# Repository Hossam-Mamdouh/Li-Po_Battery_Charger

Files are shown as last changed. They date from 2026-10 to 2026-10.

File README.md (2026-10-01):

PowerCore 3V3

USB-C 1S Li-Po Power Management & 3.3 V Supply PCB

PowerCore 3V3 is a compact power-management board for a single-cell
Li-Po battery. It combines USB-C input, Li-Po charging, system
power-path management, battery protection, and a regulated 3.3 V output.

Features

USB-C 5 V power input

1S Li-Po battery support

MCP73871 charger with system power-path management

DW01A + FS8205A battery protection

TPS63802 buck-boost regulator

Regulated 3.3 V output

Designed for up to 500 mA system load

Approximately 500 mA maximum programmed charge current

USB input PTC protection

Charge/status indication LEDs

Power Architecture

USB-C 5 V
    |
    v
Input Protection
    |
    v
MCP73871 Charger + Power Path
    |                    |
    v                    v
1S Li-Po               VSYS
    |                    |
    v                    v
DW01A + FS8205A      TPS63802
Battery Protection   Buck-Boost
                         |
                         v
                       3.3 V
                         |
                         v
                    System Load

Main Components

Reference   Component      Function

U2          MCP73871       Li-Po charger and power-path controller
U3          DW01A          Battery protection controller
Q1          FS8205A        Dual N-channel MOSFET protection switch
U4          TPS63802       Buck-boost regulator
F1          1.5 A PTC      USB input over-current protection
J1          USB-C          5 V power input
Battery     JST-PH 2-pin   1S Li-Po connection

Charger Configuration

Charge Current

PROG1 = 2 kΩ

Programs approximately 500 mA maximum charge current.

The actual charging current is reduced when system load consumes part of
the available input power.

Termination Current

PROG3 = 20 kΩ

Sets approximately 50 mA termination current.

Input Current Mode

SEL = +5V_USB

The charger uses the higher-current adapter mode rather than the 500 mA
USB mode.

Other Settings

CE pulled high → charging enabled

TE# tied to GND → safety timer enabled

THERM uses a fixed 10 kΩ resistor to GND

VPCC tied to +5V_USB

PROG2 pulled high through 10 kΩ

PG# pulled high through 10 kΩ

STAT1 / STAT2 provide status indication

Battery Protection

The protection stage uses a DW01A controller and FS8205A dual MOSFET.

For the selected FUXINSEMI FS8205A:

Pin 1 → S1
Pin 2 → D1/D2
Pin 3 → S2
Pin 4 → G2
Pin 5 → D1/D2
Pin 6 → G1

Pins 2 and 5 are the common drain connection and must be electrically
connected.

External connections:

Q1 S1      → B-
Q1 S2      → GND / P-
Q1 G1      → DW01A OD
Q1 G2      → DW01A OC
Q1 D1/D2   → common drain node

DW01A current sense:

CSI → 1 kΩ → GND / P-

3.3 V Regulation

The TPS63802 maintains a regulated 3.3 V rail from the 1S battery/system
rail.

Intended load: 500 mA

Inductor: 0.47 µH

Input capacitor: 10 µF

Output capacitor: 22 µF

Feedback: 511 kΩ / 91 kΩ

EN: VSYS

MODE: GND

The buck-boost topology allows 3.3 V regulation as battery voltage moves
above and below the output voltage.

USB-C Interface

The USB-C connector is configured as a power input.

CC1 → 5.1 kΩ → GND
CC2 → 5.1 kΩ → GND

Input decoupling and transient protection are included.

Battery Connector

The current schematic uses:

Battery Pin 2 → VBAT (+)
Battery Pin 1 → B- (-)

JST-PH pin numbering does not inherently define battery polarity. Verify
the actual battery cable/mating connector pinout before connection.

Clearly mark + and − on the PCB.

Power Budget

The intended system load is:

3.3 V × 500 mA = 1.65 W

The programmed 500 mA battery charge current is a maximum. Actual charge
current depends on system load, USB supply capability, regulator
efficiency, and charger operating conditions.

PCB Layout Guidelines

Keep TPS63802 input/output capacitors close to the IC.

Keep the 0.47 µH inductor close to the switching pins.

Keep the FB trace away from switching nodes.

Use short, low-impedance high-current paths.

Place USB input protection close to the USB-C connector.

Use appropriate copper width for battery and system power paths.

Provide solid ground copper and thermal areas.

Clearly mark battery polarity.

Design Status

Revision: A
Status: Prototype / Engineering Design

Before manufacturing, verify:

Schematic ERC

PCB DRC

Q1 symbol-to-footprint pin mapping

Battery connector pinout

PTC fuse rating and thermal derating

USB-C input capability

TPS63802 thermal performance

Charger behavior under simultaneous load and charging

Battery protection thresholds

Applications

Embedded systems

IoT devices

Portable electronics

Battery-powered sensors

ESP32-based products

Automation systems

Custom electronics prototypes

Tools

KiCad 10.x

LCSC components where applicable

Author

Hossam Mamdouh
Embedded Systems Engineer

Portfolio: https://hossam-mamdouh.github.io/

License

Choose an appropriate hardware/software license before public release.

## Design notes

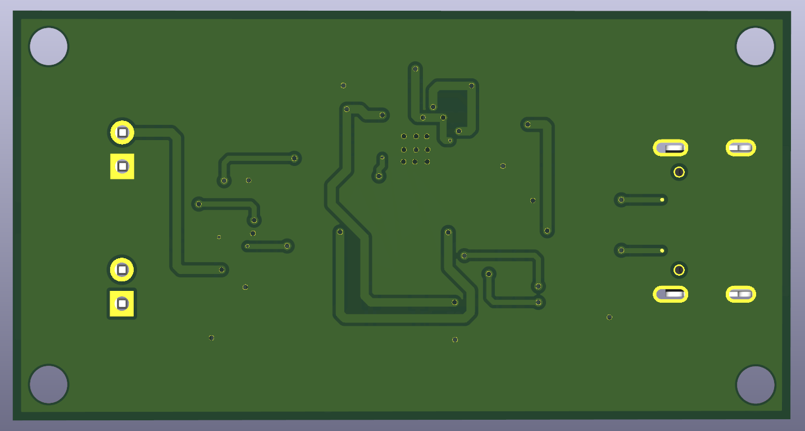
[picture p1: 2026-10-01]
Photos/Bottom.png

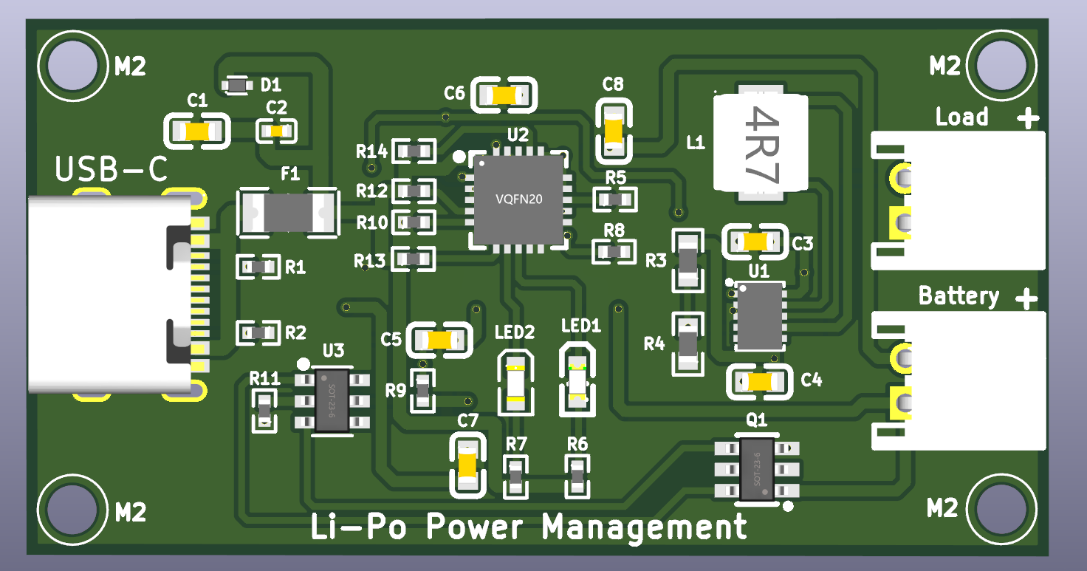
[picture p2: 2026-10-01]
Photos/Top.png

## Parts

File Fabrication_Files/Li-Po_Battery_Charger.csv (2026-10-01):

Reference | Qty | Value | DNP | Exclude from BOM | Exclude from Board | Footprint | Datasheet | LCSC
Battery1,Load1 | 2 | S2B-PH-K-S(LF)(SN) |  |  |  | lcsc_footprints:C173752_CONN-TH_S2B-PH-K-S-LF-SN | https://www.lcsc.com/datasheet/lcsc_datasheet_2304140030_JST-S2B-PH-K-S-LF-SN_C173752.pdf | C173752
C1,C3,C6,C7,C8 | 5 | 10uF |  |  |  | lcsc_footprints:C3039641_C0603 | https://wmsc.lcsc.com/wmsc/upload/file/pdf/v2/lcsc/2206171701_Murata-Electronics-GCM188D70J106ME36D_C3039641.pdf | C3039641
C2 | 1 | 100nF |  |  |  | lcsc_footprints:C5448791_C0402 | https://wmsc.lcsc.com/wmsc/upload/file/pdf/v2/lcsc/2403281711_CCTC-TCC0402X7R104K500AT_C5448791.pdf | C5448791
C4 | 1 | 22uF |  |  |  | lcsc_footprints:C22367828_C0603 | https://wmsc.lcsc.com/wmsc/upload/file/pdf/v2/lcsc/2403261048_Chinocera-HGC0603R5226M160NTHJ_C22367828.pdf | C22367828
C5 | 1 | 100nF |  |  |  | lcsc_footprints:C5137616_C0603 | https://wmsc.lcsc.com/wmsc/upload/file/pdf/v2/lcsc/2208181800_FOJAN-FCC0603B104K101CT_C5137616.pdf | C5137616
D1 | 1 | ESD9B5V |  |  |  | lcsc_footprints:C2905646_SOD-923_L0_8-W0_6-LS1_0-BI-1 | https://wmsc.lcsc.com/wmsc/upload/file/pdf/v2/lcsc/2110250930_TECH-PUBLIC-ESD9B5V_C2905646.pdf | C2905646
F1 | 1 | 1.5A |  |  |  | lcsc_footprints:C118413_F1206 | https://www.lcsc.com/datasheet/lcsc_datasheet_2304140030_Littelfuse-1206L150THWR_C118413.pdf | C118413
L1 | 1 | 0.47 µH |  |  |  | lcsc_footprints:C285747_IND-SMD_L4_0-W4_0_CHILISIN_MHCI04012N |  | C285747
LED1 | 1 | 0603 |  |  |  | lcsc_footprints:C2286_LED-SMD_L1_6-W0_8-R-RD | https://www.lcsc.com/datasheet/lcsc_datasheet_1810231112_Hubei-KENTO-Elec-KT-0603R_C2286.pdf | C2286
LED2 | 1 | PSC-1608U52GC-G4 |  |  |  | lcsc_footprints:C22371297_LED0603-RD_GREEN | https://wmsc.lcsc.com/wmsc/upload/file/pdf/v2/lcsc/2403281525_HONGLITRONIC-Hongli-Zhihui--HONGLITRONIC-PSC-1608U52GC-G4_C22371297.pdf | C22371297
Q1 | 1 | FS8205A_C908265 |  |  |  | lcsc_footprints:C908265_SOT-23-6_L2_9-W1_6-P0_95-LS2_8-BR | https://www.lcsc.com/datasheet/lcsc_datasheet_2010271837_FUXINSEMI-FS8205A_C908265.pdf | C908265
R1,R2 | 2 | 5.1KΩ |  |  |  | lcsc_footprints:C25905_R0402 | https://www.lcsc.com/datasheet/lcsc_datasheet_2206010045_UNI-ROYAL-Uniroyal-Elec-0402WGF5101TCE_C25905.pdf | C25905
R3 | 1 | 511kΩ |  |  |  | lcsc_footprints:C861454_R0603 | https://wmsc.lcsc.com/wmsc/upload/file/pdf/v2/lcsc/2210190000_YAGEO-RT0603BRD07511KL_C861454.pdf | C861454
R4 | 1 | 91 kΩ |  |  |  | lcsc_footprints:C2907077_R0603 | https://wmsc.lcsc.com/wmsc/upload/file/pdf/v2/lcsc/2308241947_FOJAN-FRC0603F9102TS_C2907077.pdf | C2907077
R5 | 1 | 2KΩ |  |  |  | lcsc_footprints:C4109_R0402 | https://www.lcsc.com/datasheet/lcsc_datasheet_2206010230_UNI-ROYAL-Uniroyal-Elec-0402WGF2001TCE_C4109.pdf | C4109
R6,R7,R11 | 3 | 1KΩ |  |  |  | lcsc_footprints:C11702_R0402 | https://www.lcsc.com/datasheet/lcsc_datasheet_2206010216_UNI-ROYAL-Uniroyal-Elec-0402WGF1001TCE_C11702.pdf | C11702
R8 | 1 | 20 kΩ |  |  |  | lcsc_footprints:C93942_R0402 | https://wmsc.lcsc.com/wmsc/upload/file/pdf/v2/lcsc/2304140030_YAGEO-RC0402FR-0720KL_C93942.pdf | C93942
R9 | 1 | 100Ω |  |  |  | lcsc_footprints:C106232_R0402 | https://www.lcsc.com/datasheet/lcsc_datasheet_2304140030_YAGEO-RC0402FR-07100RL_C106232.pdf | C106232
R10,R12,R13,R14 | 4 | 10kΩ |  |  |  | lcsc_footprints:C326912_R0402 | https://www.lcsc.com/datasheet/lcsc_datasheet_1811011622_YAGEO-RT0402DRE0710KL_C326912.pdf | C326912
U1 | 1 | TPS63802DLAR |  |  |  | lcsc_footprints:C2845237_VSON-10_L3_0-W2_0-P0_50-TL | https://wmsc.lcsc.com/wmsc/upload/file/pdf/v2/lcsc/2302220830_Texas-Instruments-TPS63802DLAR_C2845237.pdf | C2845237
U2 | 1 | MCP73871-2CCI/ML |  |  |  | lcsc_footprints:C5121473_QFN-20_L4_0-W4_0-P0_50-BL-EP2_7 | https://wmsc.lcsc.com/wmsc/upload/file/pdf/v2/lcsc/2212031600_Microchip-Tech-MCP73871-2CCI-ML_C5121473.pdf | C5121473
U3 | 1 | DW01A |  |  |  | lcsc_footprints:C42459937_SOT-23-6_L2_9-W1_6-P0_95-LS2_8-BL | None | C42459937
USB-C1 | 1 | TYPE-C 16P(073) |  |  |  | lcsc_footprints:C668624_USB-C-SMD_TYPE-C16PIN_C668624 | https://www.lcsc.com/datasheet/lcsc_datasheet_2006181823_SHOU-HAN-TYPE-C-16P-073_C668624.pdf | C668624

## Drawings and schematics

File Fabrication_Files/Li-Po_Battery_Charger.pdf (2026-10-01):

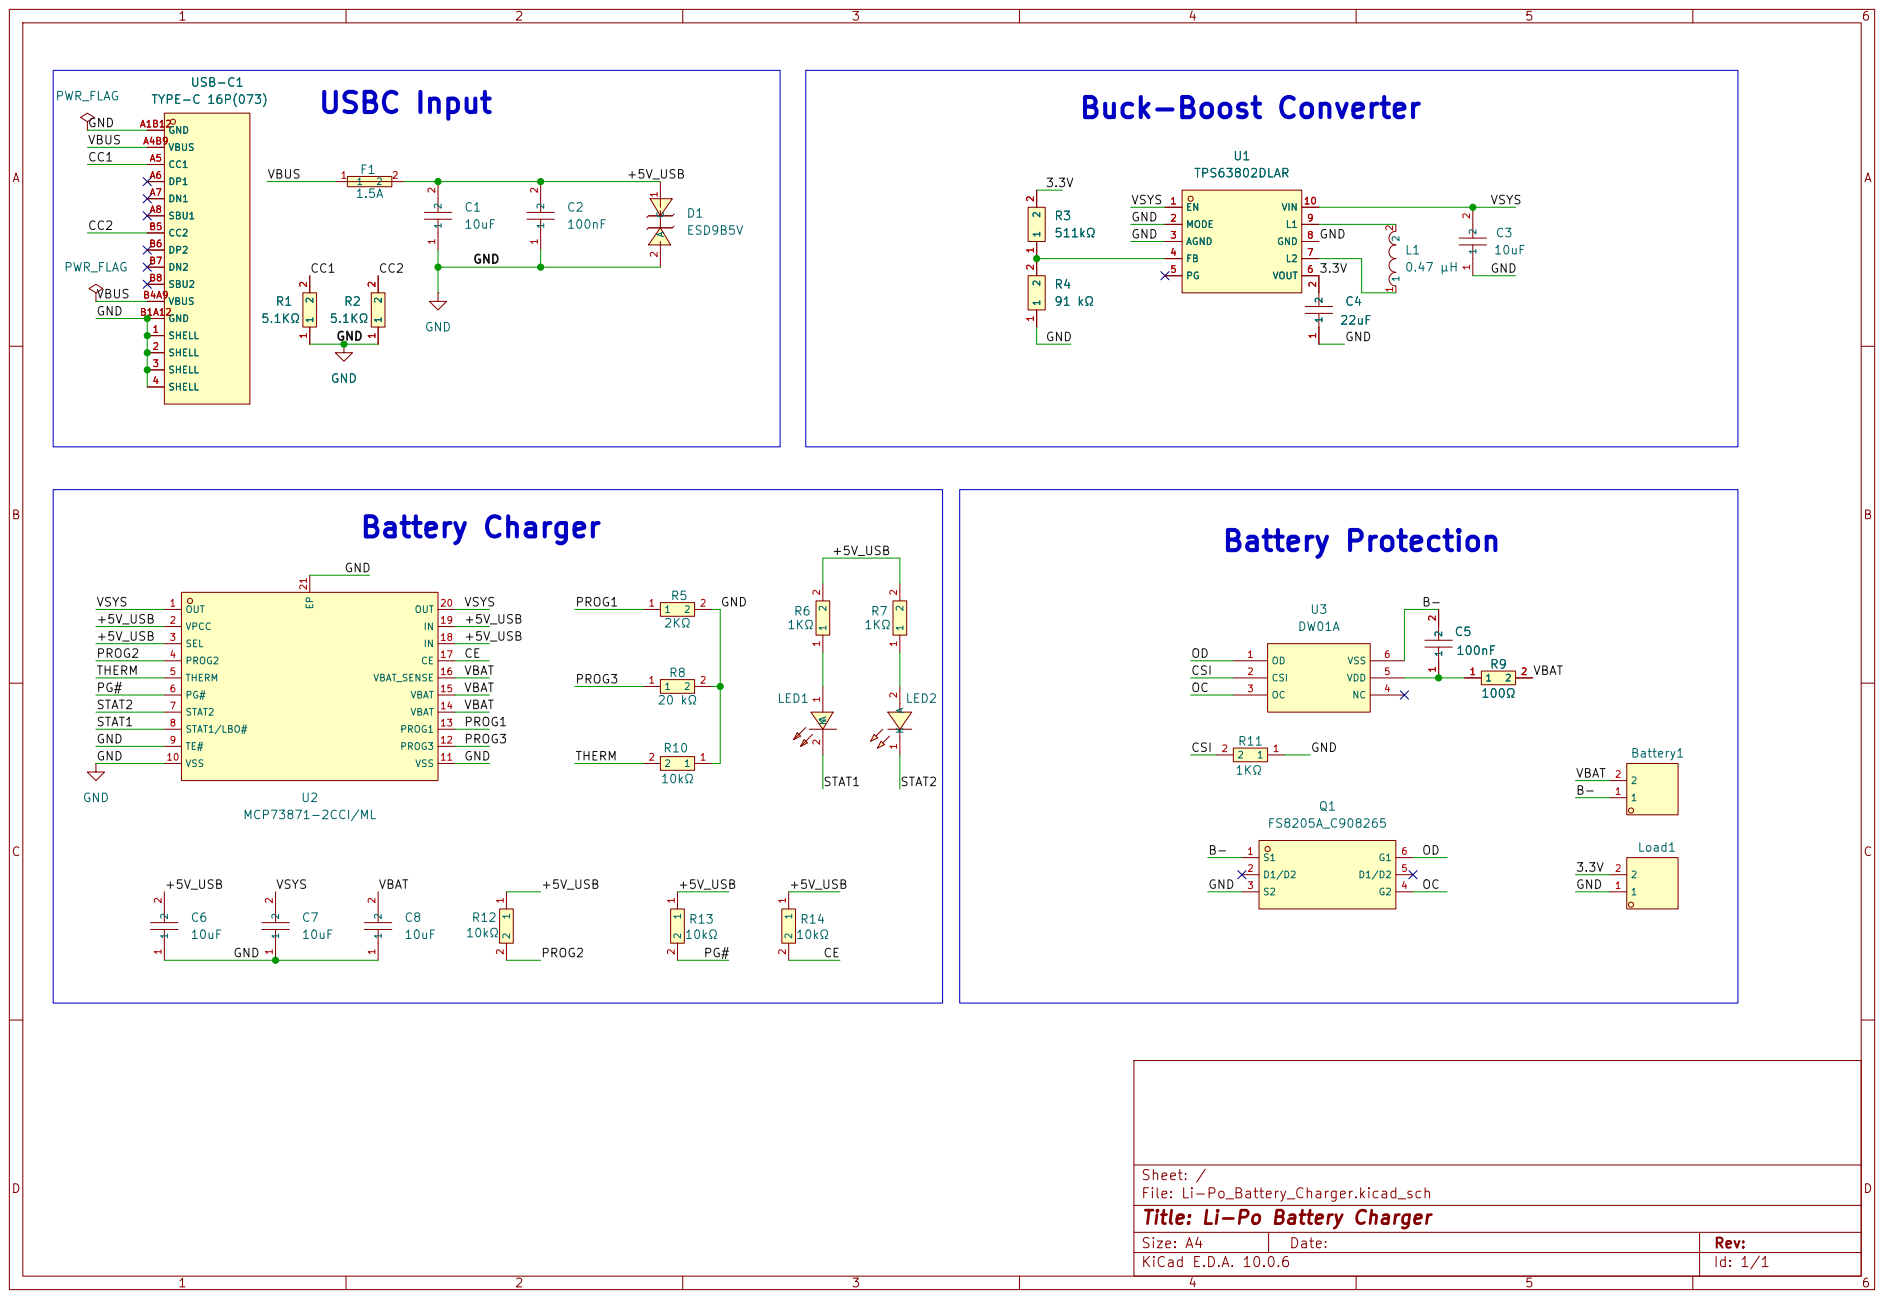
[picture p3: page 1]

Sheet: /
File: Li-Po_Battery_Charger.kicad_sch
Title: Li-Po Battery Charger

Size: A4 | Rev:
KiCad E.D.A. 10.0.6 | Id: 1/1

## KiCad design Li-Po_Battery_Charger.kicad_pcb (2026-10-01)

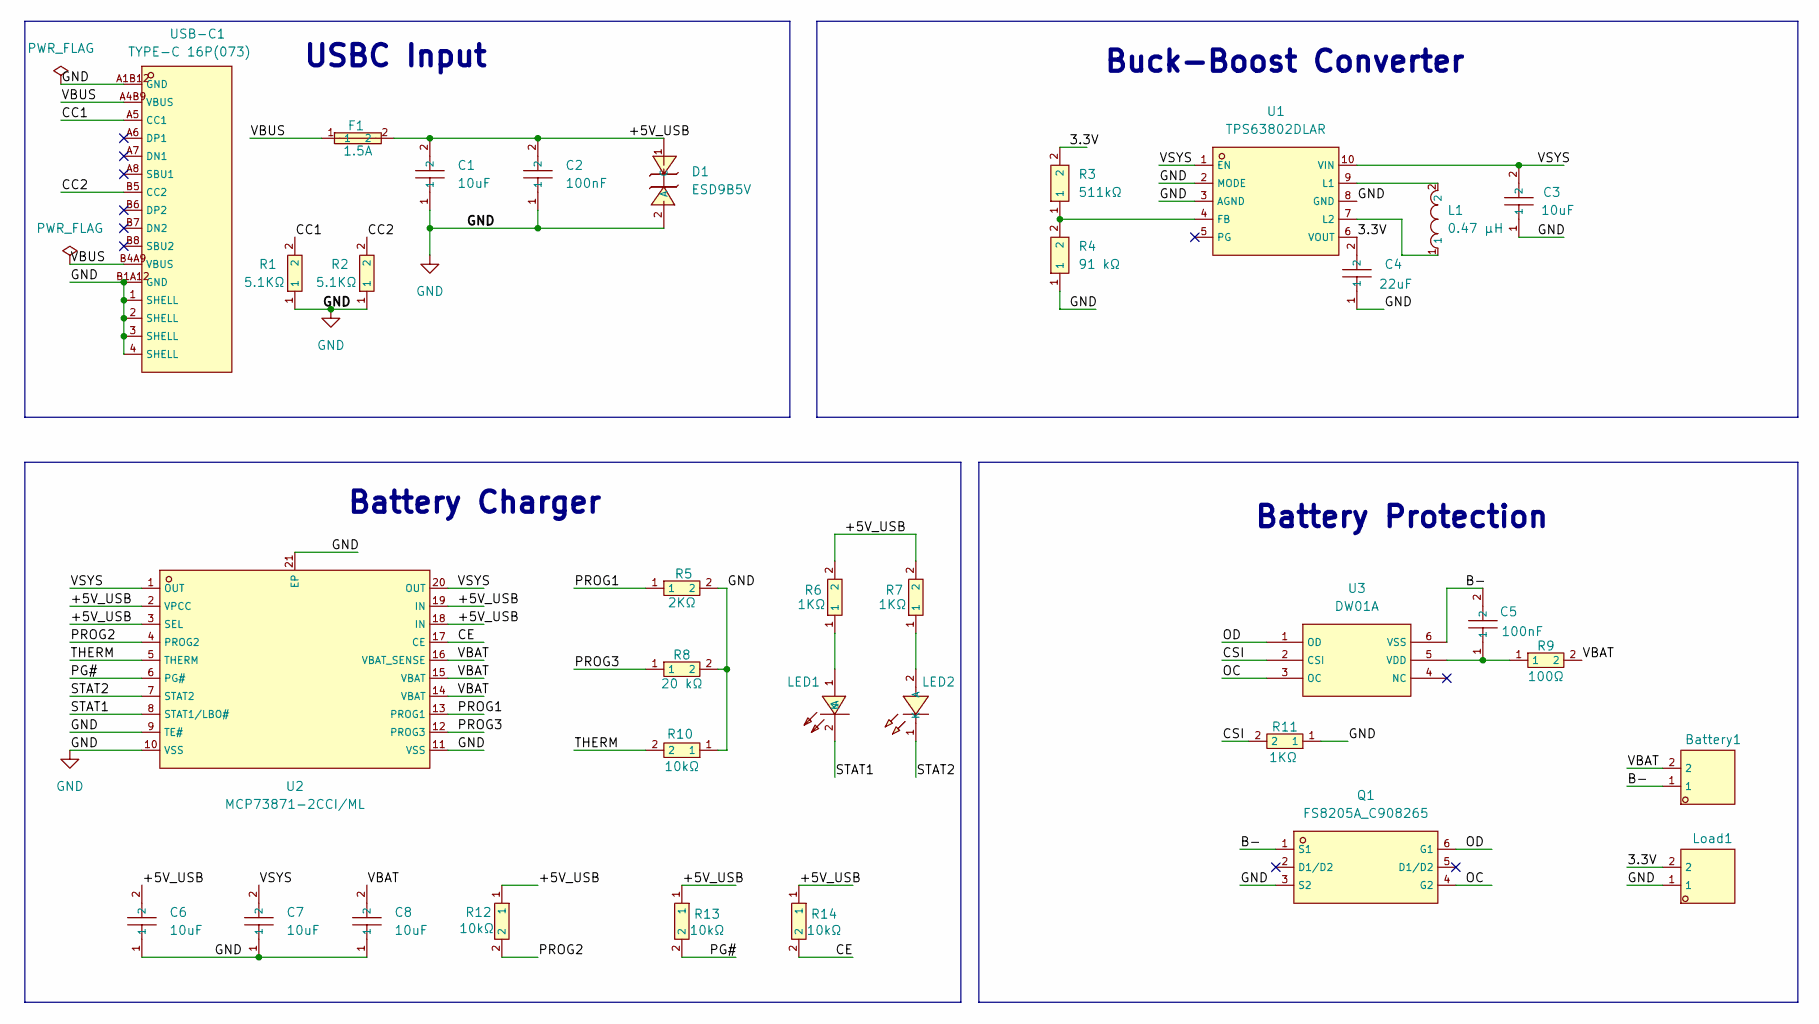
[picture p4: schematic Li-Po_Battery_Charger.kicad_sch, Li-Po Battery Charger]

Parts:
Battery1: S2B-PH-K-S(LF)(SN); C173752_CONN-TH_S2B-PH-K-S-LF-SN; LCSC C173752
C1, C3, C6, C7, C8: 10uF; C3039641_C0603; LCSC C3039641
C2: 100nF; C5448791_C0402; LCSC C5448791
C4: 22uF; C22367828_C0603; LCSC C22367828
C5: 100nF; C5137616_C0603; LCSC C5137616
D1: ESD9B5V; C2905646_SOD-923_L0_8-W0_6-LS1_0-BI-1; LCSC C2905646
F1: 1.5A; C118413_F1206; LCSC C118413
L1: 0.47 µH; C285747_IND-SMD_L4_0-W4_0_CHILISIN_MHCI04012N; LCSC C285747
LED1: 0603; C2286_LED-SMD_L1_6-W0_8-R-RD; LCSC C2286
LED2: PSC-1608U52GC-G4; C22371297_LED0603-RD_GREEN; LCSC C22371297
Load1: S2B-PH-K-S(LF)(SN); C173752_CONN-TH_S2B-PH-K-S-LF-SN; LCSC C173752
Q1: FS8205A_C908265; C908265_SOT-23-6_L2_9-W1_6-P0_95-LS2_8-BR; LCSC C908265
R1, R2: 5.1KΩ; C25905_R0402; LCSC C25905
R3: 511kΩ; C861454_R0603; LCSC C861454
R4: 91 kΩ; C2907077_R0603; LCSC C2907077
R5: 2KΩ; C4109_R0402; LCSC C4109
R6, R7, R11: 1KΩ; C11702_R0402; LCSC C11702
R8: 20 kΩ; C93942_R0402; LCSC C93942
R9: 100Ω; C106232_R0402; LCSC C106232
R10, R12, R13, R14: 10kΩ; C326912_R0402; LCSC C326912
U1: TPS63802DLAR; C2845237_VSON-10_L3_0-W2_0-P0_50-TL; LCSC C2845237
U2: MCP73871-2CCI/ML; C5121473_QFN-20_L4_0-W4_0-P0_50-BL-EP2_7; LCSC C5121473
U3: DW01A; C42459937_SOT-23-6_L2_9-W1_6-P0_95-LS2_8-BL; LCSC C42459937
USB-C1: TYPE-C 16P(073); C668624_USB-C-SMD_TYPE-C16PIN_C668624; LCSC C668624

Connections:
/3.3V: C4.2, Load1.2, R3.2, U1.6 (VOUT); also elsewhere on the board
/+5V_USB: C1.2, C2.2, C6.2, D1.1 (C), F1.2, R6.2, R7.2, R12.1, R13.1, R14.1, U2.2 (VPCC), U2.3 (SEL), U2.18 (IN), U2.19 (IN)
/B-: Battery1.1, C5.2, Q1.1 (S1), U3.6 (VSS); also elsewhere on the board
/CC1: R1.2, USB-C1.A5 (CC1); also elsewhere on the board
/CC2: R2.2, USB-C1.B5 (CC2); also elsewhere on the board
/CE: R14.2, U2.17 (CE)
/CSI: R11.2, U3.2 (CSI)
/OC: Q1.4 (G2), U3.3 (OC)
/OD: Q1.6 (G1), U3.1 (OD)
/PG#: R13.2, U2.6 (PG#)
/PROG1: R5.1, U2.13 (PROG1)
/PROG2: R12.2, U2.4 (PROG2)
/PROG3: R8.1, U2.12 (PROG3)
/STAT1: LED1.2 (K), U2.8 (STAT1/LBO#)
/STAT2: LED2.1 (K), U2.7 (STAT2)
/THERM: R10.2, U2.5 (THERM)
/VBAT: Battery1.2, C8.2, R9.2, U2.14 (VBAT), U2.15 (VBAT), U2.16 (VBAT_SENSE); also elsewhere on the board
/VBUS: F1.1, USB-C1.A4B9 (VBUS), USB-C1.B4A9 (VBUS); also elsewhere on the board
/VSYS: C3.2, C7.2, U1.1 (EN), U1.10 (VIN), U2.1 (OUT), U2.20 (OUT)
GND: C1.1, C2.1, C3.1, C4.1, C6.1, C7.1, C8.1, D1.2 (A), Load1.1, Q1.3 (S2), R1.1, R2.1, R4.1, R5.2, R8.2, R10.1, R11.1, U1.2 (MODE), U1.3 (AGND), U1.8 (GND), U2.9 (TE#), U2.10 (VSS), U2.11 (VSS), U2.21 (EP), USB-C1.1 (SHELL), USB-C1.2 (SHELL), USB-C1.3 (SHELL), USB-C1.4 (SHELL), USB-C1.A1B12 (GND), USB-C1.B1A12 (GND); also elsewhere on the board
unnamed: LED1.1 (A), R6.1
unnamed: LED2.2 (A), R7.1
unnamed: R3.1, R4.2, U1.4 (FB)
unnamed: L1.2, U1.9 (L1)
unnamed: L1.1, U1.7 (L2)
unnamed: C5.1, R9.1, U3.5 (VDD)

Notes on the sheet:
USBC Input
Battery Charger
Battery Protection
Buck-Boost Converter

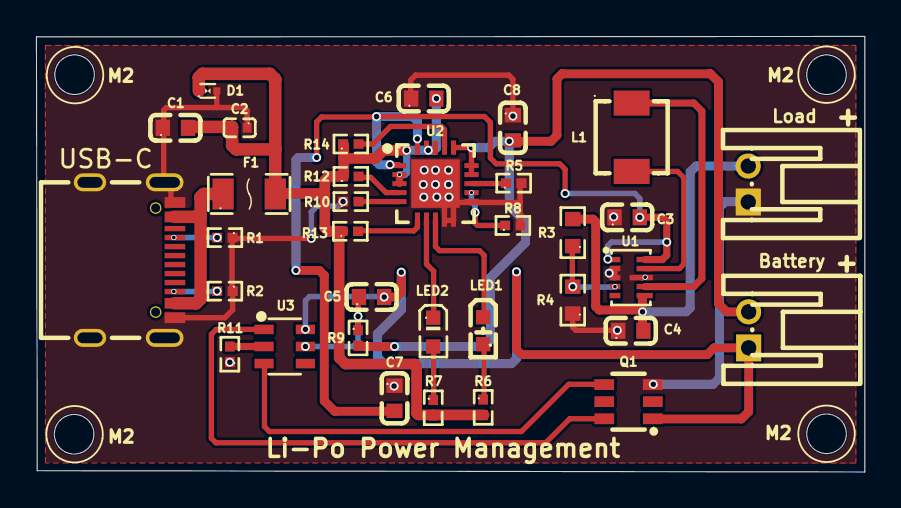
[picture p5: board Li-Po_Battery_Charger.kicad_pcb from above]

Board: 2 copper layers, 46.0 x 24.2 mm, 34 parts (0 on the bottom side), 26 nets.

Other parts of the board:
Battery: S2B-PH-K-S(LF)(SN); C173752_CONN-TH_S2B-PH-K-S-LF-SN
Load: S2B-PH-K-S(LF)(SN); C173752_CONN-TH_S2B-PH-K-S-LF-SN
USB-C: TYPE-C 16P(073); C668624_USB-C-SMD_TYPE-C16PIN_C668624

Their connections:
/3.3V: Load.2; also elsewhere on the board
/B-: Battery.1; also elsewhere on the board
/CC1: USB-C.A5 (CC1); also elsewhere on the board
/CC2: USB-C.B5 (CC2); also elsewhere on the board
/VBAT: Battery.2; also elsewhere on the board
/VBUS: USB-C.A4B9 (VBUS), USB-C.B4A9 (VBUS); also elsewhere on the board
GND: Load.1, USB-C.1 (SHELL), USB-C.2 (SHELL), USB-C.3 (SHELL), USB-C.4 (SHELL), USB-C.A1B12 (GND), USB-C.B1A12 (GND); also elsewhere on the board

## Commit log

2026-09-28 Add title to the Schematic
    [Li-Po_Battery_Charger.kicad_sch]
2026-09-28 Add USB-C Input
    [Li-Po_Battery_Charger.kicad_sch]
2026-09-28 Add Battery Charger and Buck Converter
    [Li-Po_Battery_Charger.kicad_sch]
2026-09-28 Initial PCB Layout
    [Li-Po_Battery_Charger.kicad_pcb, Li-Po_Battery_Charger.kicad_sch]
2026-09-28 Final Design
    [Li-Po_Battery_Charger-B_Cu.gbr, Li-Po_Battery_Charger-B_Mask.gbr, Li-Po_Battery_Charger-B_Paste.gbr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]
2026-10-01 Final Production Version
    [Li-Po_Battery_Charger-B_Cu.gbr, Li-Po_Battery_Charger-B_Mask.gbr, Li-Po_Battery_Charger-B_Paste.gbr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]
2026-10-01 Add README for PowerCore 3V3 documentation
    Added detailed documentation for PowerCore 3V3, including features, components, charger configuration, battery protection, and PCB layout guidelines.
